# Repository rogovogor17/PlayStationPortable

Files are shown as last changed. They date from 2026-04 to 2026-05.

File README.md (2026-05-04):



[][platformio-url]
[][esp32-url]
[][cpp-url]
[][3dprint-url]
[][license-url]

<br />
<div align="center">
  <a href="https://github.com/rogovogor17/PlayStationPortable">
    
  </a>

  <h3 align="center">DIY PlayStation Portable (PSP)</h3>
  <h4 align="center">ESP32 + TFT Handheld with Battle City Game</h4>

<div align="center">

**[Getting Started](#getting-started)** • **[Hardware](#hardware)** • **[Game](#game-implementation)** • **[Case](#3d-printed-case)** • **[Roadmap](#roadmap)**

</div>
</div>

<details>
  <summary>Table of Contents</summary>
  <ol>
    <li><a href="#about-the-project">About The Project</a>
      <ul>
        <li><a href="#key-features">Key Features</a></li>
      </ul>
    </li>
    <li><a href="#getting-started">Getting Started</a>
      <ul>
        <li><a href="#prerequisites">Prerequisites</a></li>
        <li><a href="#firmware-upload">Firmware Upload</a></li>
      </ul>
    </li>
    <li><a href="#hardware">Hardware</a>
      <ul>
        <li><a href="#components">Components</a></li>
        <li><a href="#schematic--pinout">Schematic & Pinout</a></li>
      </ul>
    </li>
    <li><a href="#game-implementation">Game Implementation</a>
      <ul>
        <li><a href="#controls">Controls</a></li>
        <li><a href="#game-mechanics">Game Mechanics</a></li>
        <li><a href="#class-structure">Class Structure</a></li>
      </ul>
    </li>
    <li><a href="#3d-printed-case">3D Printed Case</a></li>
    <li><a href="#roadmap">Roadmap</a></li>
	<li><a href="#contributors">Contributors</a></li>
    <li><a href="#references">References</a></li>

  </ol>
</details>

---

## About The Project

DIY portable game console inspired by classic handhelds, built around the ESP32 microcontroller and a 480×320 TFT display. The device plays a custom Battle City‑like tank game and is enclosed in a fully 3D‑printed case. All hardware schematics, firmware, and 3D models are provided.

### Key Features

| Feature | Description |
| --- | --- |
| **Custom Hardware** | ESP32‑WROOM, ILI9488 TFT 3.5″/3.95″, 9 physical buttons, Li‑Po battery support |
| **Full Game** | Battle City clone with tanks, enemies, walls, bonuses, and increasing levels |
| **3D Printed Case** | Ergonomic shell designed in CAD, printed on a standard FDM printer |
| **PlatformIO Project** | Modern C++ (GNU++14), easy to build and upload |
| **Modular Code** | Object‑oriented design: `Tank`, `Bullet`, `Wall`, etc. |

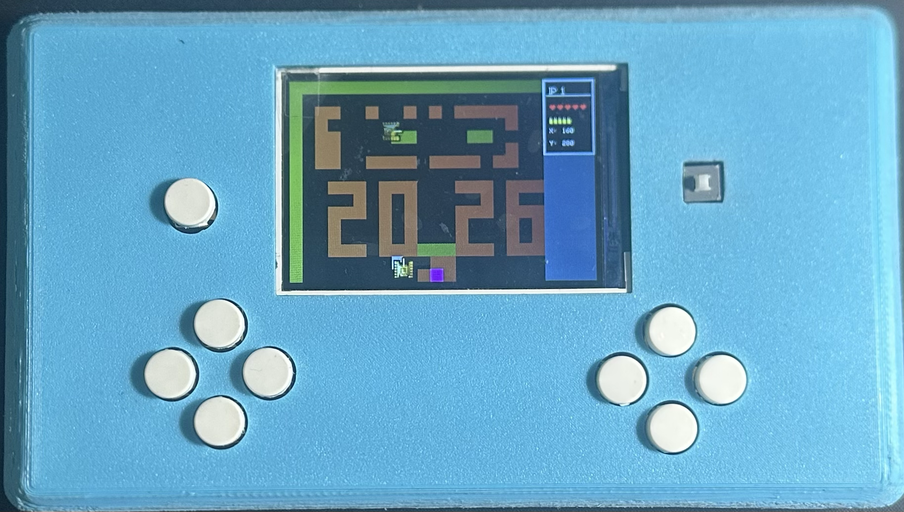
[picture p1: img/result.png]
Gameplay screenshot Battle City on ESP32


<p align="right">(<a href="#readme-top">back to top</a>)</p>

---

## Getting Started

### Prerequisites

| Tool / Hardware | Version / Spec | Purpose |
| --- | --- | --- |
| **PlatformIO** | Core 6.0+ / IDE VS Code | Build & upload firmware |
| **ESP32 board** | DOIT ESP32 DEVKIT V1 (WROOM‑32) | Main controller |
| **TFT display** | 3.5″/3.95″ ILI9488 SPI 480×320  | Graphics output |
| **9 tactile buttons** | Through‑hole 6×6 mm | Player input |
| **USB‑UART cable** | Type-C data cable | Programming & power |

### Firmware Upload

PlatformIO may be used in two different ways: as VS Code extension (recommended) or as command line interface (CLI).

#### 1. PlatformIO Core (CLI)

```bash
#Install using Python3
pip install -U platformio

#Checking PlatformIO
pio --version
```

#### 2. Open project

```bash
#Clone repo
git clone https://github.com/rogovogor17/PlayStationPortable
cd PlayStationPortable
```

#### 3. Port Settings

In file `platformio.ini` (line `upload_port`) you can add using port for your board, for example:

```ini
upload_port = COM9    			   (Windows)
upload_port = /dev/ttyUSB0  	   (Linux)
upload_port = /dev/cu.usbserial-*  (macOS)
```

If you comment the line, PlatformIO will try to identify the port automatically .

#### 4. Building and firmware

```bash
#CLI: in root directory
pio run --target upload --target monitor
```

First running may take a few minutes - PlatformIO will download necessary libraries and toolchain ESP32.

#### 5. Important notes for ESP32

> [!NOTE]
> If the firmware does not load, hold down the **BOOT** button (or press it once when the process starts) – this will put the ESP32 into programming mode.

> [!WARNING]
> When using a battery, the board power must be disconnected during flashing (to avoid conflicts).

> [!NOTE]
> After a successful boot, the game will appear on the display. If the screen is blank, check the display connection and the settings in the TFT_eSPI library's 'User_Setup.h' (the project already includes the correct configuration).

<p align="right">(<a href="#readme-top">back to top</a>)</p>

---

## Hardware

### Components

| Component | Model / Value | Quantity |
| --- | --- | --- |
| Microcontroller | ESP32‑WROOM‑32 (DOIT DevKit V1) | 1 |
| Display | TFT 3.5″ or 3.95″, ILI9488 controller | 1 |
| Buttons | D-Pad (4) + Fire + Start + 3 extra | 9 |
| Battery | 3.7 V Li‑Po | 2 |
| Charging module | TP4056 | 1 |
| Miscellaneous | Protoboard, wires, headers, Type-C | – |

### Schematic & Pinout

| ESP32 Pin | Function | Connected To |
| --- | --- | --- |
| GPIO 15 | TFT CS | Display CS |
| GPIO 2 | TFT DC | Display DC |
| GPIO 4 | TFT RST | Display RST |
| GPIO 23 | TFT MOSI | Display SDI/MOSI |
| GPIO 18 | TFT SCK | Display SCK |
| GPIO 19 | TFT MISO | Display SDO/MISO |
| GPIO 17 | Button UP | Pull‑up + button to GND |
| GPIO 33 | Button DOWN | Pull‑up + button to GND |
| GPIO 25 | Button LEFT | Pull‑up + button to GND |
| GPIO 19 | Button RIGHT | Pull‑up + button to GND |
| GPIO 27 | Button FIRE | Pull‑up + button to GND |
| GPIO 26 | Button START | Pull‑up + button to GND |
| GPIO 12 | Button EXTRA 1 | Pull‑up + button to GND |
| GPIO 13 | Button EXTRA 2 | Pull‑up + button to GND |
| GPIO 14 | Button EXTRA 3 | Pull‑up + button to GND |
| GND | Common ground  | All buttons, display |
| 3.3V | Power (logic)  | Display VCC |

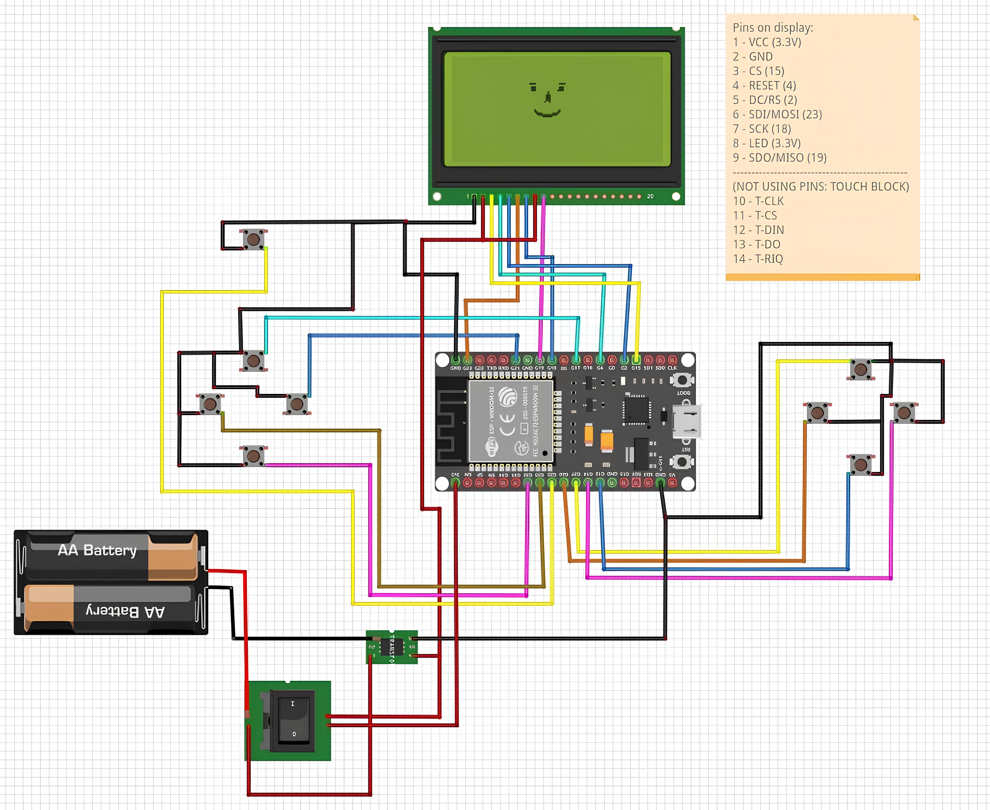
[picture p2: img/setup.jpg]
Schematic preview Schematic assemble


<p align="right">(<a href="#readme-top">back to top</a>)</p>

---

## Game Implementation

The firmware is written in **C++ (GNU++14)** and structured as a PlatformIO project. It uses the **TFT_eSPI** library for fast SPI graphics and **Arduino framework** for GPIO handling.

### Controls

| Button | Action |
| --- | --- |
| **D‑Pad** | Move player tank |
| **Fire** | Shoot |
| **Start** | Start game / Pause |
| **Extra 1** | (reserved for future use) |
| **Extra 2** | (reserved for future use) |
| **Extra 3** | (reserved for future use) |

### Game Mechanics

- **Player tank:** moves in four directions, shoots bullets, has health & ammunition.
- **Enemy tanks:** AI bots that move randomly and shoot.
- **Walls:** brick (destructible) and steel (indestructible).
- **Base (eagle):** must be protected from enemy fire.
- **Bonuses:** star (upgrade), shovel (temporary wall), helmet (invincibility), etc. (in future)

### Class Structure

The game logic is organised into several C++ classes that encapsulate behaviour and rendering.

<details>
<summary><b>class Tank</b> (click to expand)</summary>

```cpp
class Tank {
    const size_t max_health_, max_ammunition_;
    size_t health_, ammunition_;
    size_t x_pos, y_pos;
    size_t speed_;
    TankDirection direction_ = TankDirection::UP;

    TFT_eSPI& tft_;
    TFT_eSprite* tank_sprite_;
    uint16_t background_buffer_[DEFAULT_TANK_WIDTH * DEFAULT_TANK_HEIGHT];

public:
    Tank(size_t x, size_t y, size_t health, size_t ammo, size_t speed, TFT_eSPI& tft);
    ~Tank();

    void show(void);
    void move(int x, int y);
    void set_position(size_t x, size_t y);
    void set_direction(TankDirection direction);

    size_t get_x_pos() const;
    size_t get_y_pos() const;
    size_t get_speed() const;
    size_t get_health() const;
    size_t get_ammunition() const;
};
```

</details>

Additional classes: `Bullet`, `Wall`, `EnemyTank` (inherits from `Tank`), `GameBoard`, `GameState`.

All graphics use **TFT_eSprite** buffers to avoid flickering, and the display is updated only on changed tiles to meet the ESP32’s performance limits.

<p align="right">(<a href="#readme-top">back to top</a>)</p>

---

## 3D Printed Case

The console body was designed to house the ESP32 board, TFT panel, and all buttons. It consists of three parts:

- **Front shell** with cutouts for the display and buttons.
- **Back shell** with mounting cutout for the Type-C port.
- **Back cover** for getting access to batteries.

Printing settings (common for PLA):

- Layer height: 0.2 mm
- Infill: 20% grid
- Supports: for the edges of the supporting parts of the body

The model files are available in the `case/` directory.

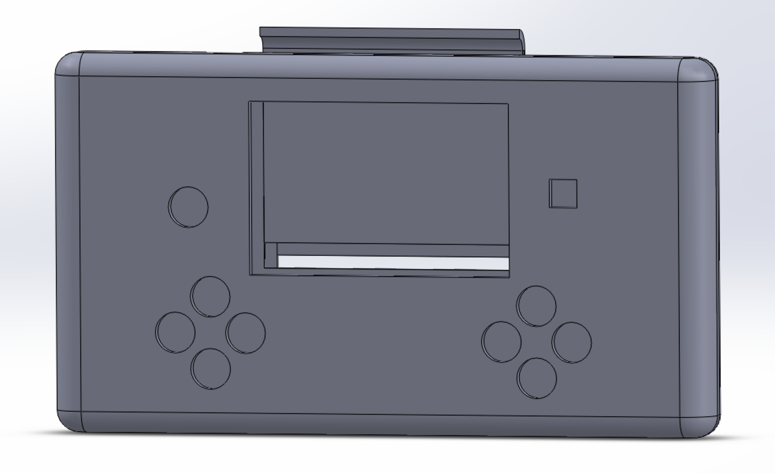
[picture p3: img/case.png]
Case preview Case assemble


<p align="right">(<a href="#readme-top">back to top</a>)</p>

---

## Roadmap

- [x] **Phase 1: Hardware**
  - [x] Schematic & prototype soldering
  - [x] Button & display integration

- [x] **Phase 2: Core Game**
  - [x] Player tank movement & shooting
  - [x] Map grid (12×8 cells, 40×40 px)
  - [x] Enemy AI, walls, base, bonuses

- [x] **Phase 3: Enclosure**
  - [x] 3D‑modeled case
  - [x] FDM printing and assembly

- [ ] **Phase 4: Polish**
  - [ ] Sound effects (buzzer or speaker)
  - [ ] Battery indicator & power management
  - [ ] Multiple levels and high‑score save

<p align="right">(<a href="#readme-top">back to top</a>)</p>

---

## Contributors

The project was created and developed by enthusiasts who believe in open source and the DIY spirit.

| Author | Role | Tasks | Contacts |
| --- | --- | --- | --- |
| Alexander Starostin | Hardware Lead  | Circuit design and soldering | [GitHub](https://github.com/Alexandr26Starostin) |
| Michael Movsesyan | Game Developer | Game design, Game code | [GitHub](https://github.com/aywert) |
| Anatoliy Rogov | 3D Designer | Case modeling/printing, components selection/ordering | [GitHub](https://github.com/rogovogor17) |

---

## References

1. **PlatformIO** — [platformio.org](https://platformio.org/)
2. **TFT_eSPI library** — [github.com/Bodmer/TFT_eSPI](https://github.com/Bodmer/TFT_eSPI)
3. **Inspiration** — classic Battle City (NES, 1985)

<p align="right">(<a href="#readme-top">back to top</a>)</p>

---

<div align="center">
  <sub>© 2026 — DIY PlayStation Portable</sub>
</div>

[platformio-shield]: https://img.shields.io/badge/PlatformIO-6.0+-F58220?style=for-the-badge&logo=platformio&logoColor=white
[platformio-url]: https://platformio.org/
[esp32-shield]: https://img.shields.io/badge/ESP32-DOIT_DevKit_V1-00B0FF?style=for-the-badge&logo=espressif&logoColor=white
[esp32-url]: https://www.espressif.com/en/products/socs/esp32
[cpp-shield]: https://img.shields.io/badge/C++-GNU++14-00599C?style=for-the-badge&logo=c%2B%2B&logoColor=white
[cpp-url]: https://isocpp.org/
[3dprint-shield]: https://img.shields.io/badge/3D_Printed-FDM-orange?style=for-the-badge&logo=thingiverse&logoColor=white
[3dprint-url]: https://www.thingiverse.com/
[license-shield]: https://img.shields.io/badge/License-MIT-green.svg?style=for-the-badge
[license-url]: LICENSE.txt

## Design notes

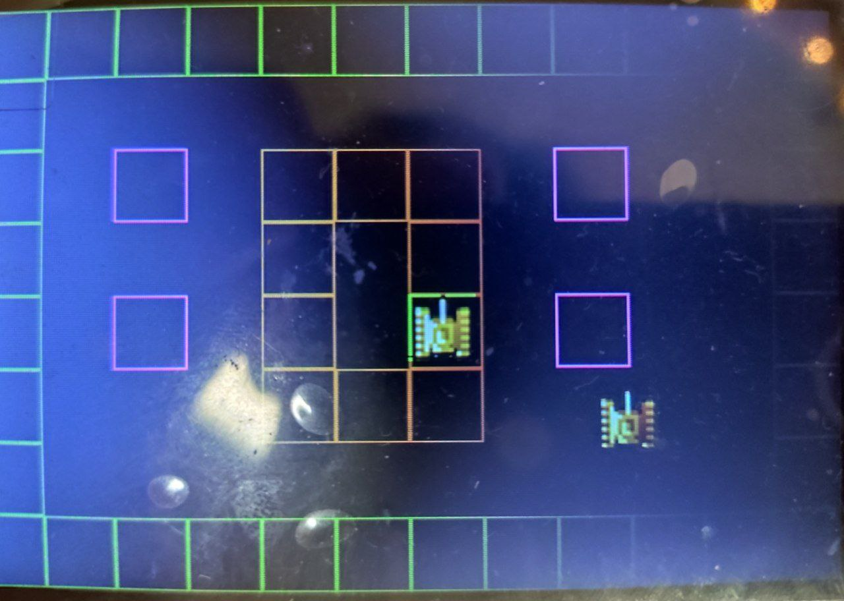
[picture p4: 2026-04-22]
img/image.png

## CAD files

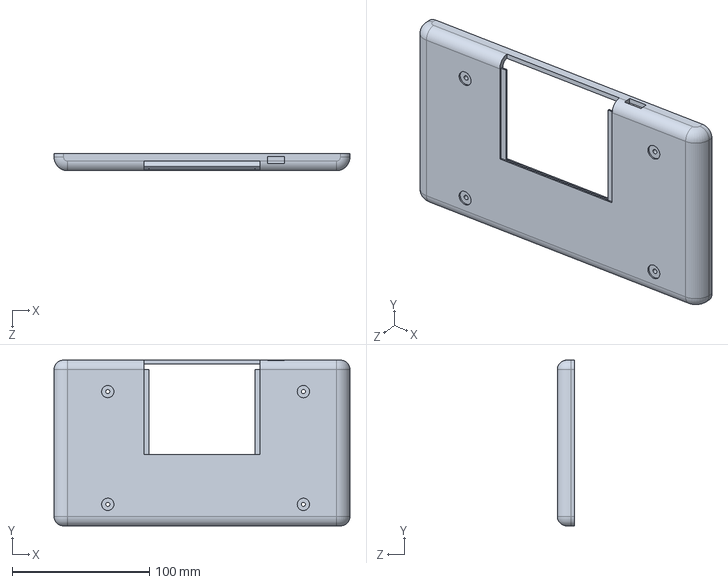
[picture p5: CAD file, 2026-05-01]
case/FrameDownMain.STEP
216.0 x 121.0 x 12.8 mm

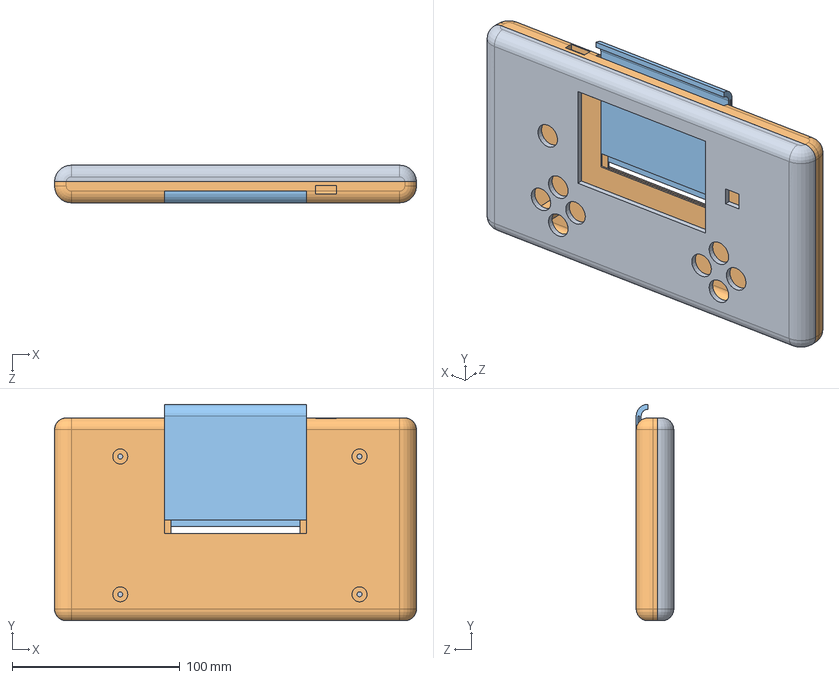
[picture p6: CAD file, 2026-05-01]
case/PSP.SLDASM
216.0 x 129.2 x 22.5 mm
FrameUP
FrameDownMain
FrameDownCover

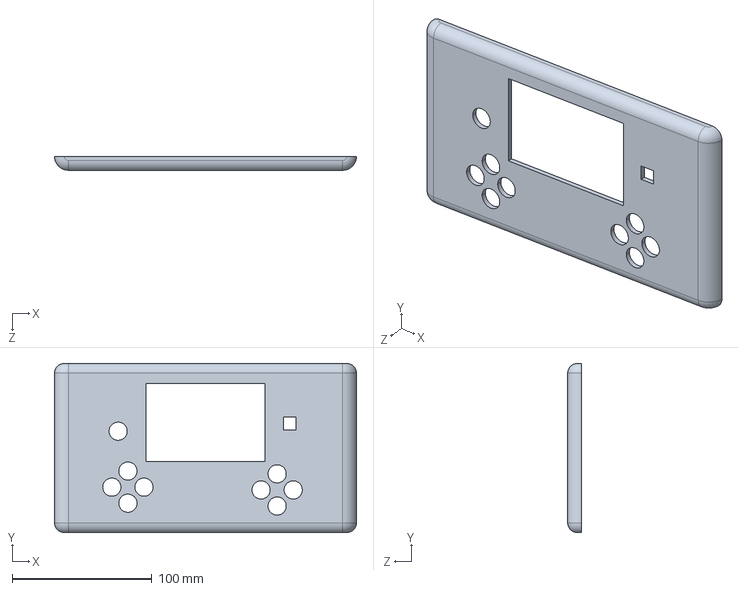
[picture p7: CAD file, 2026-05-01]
case/FrameUP.STEP
216.0 x 121.0 x 9.75 mm

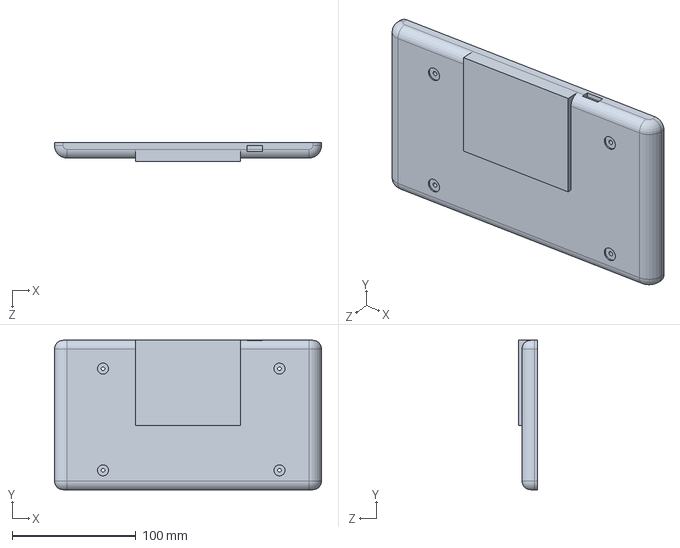
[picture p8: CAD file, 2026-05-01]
case/FrameDown.SLDPRT
216.0 x 121.0 x 15.8 mm

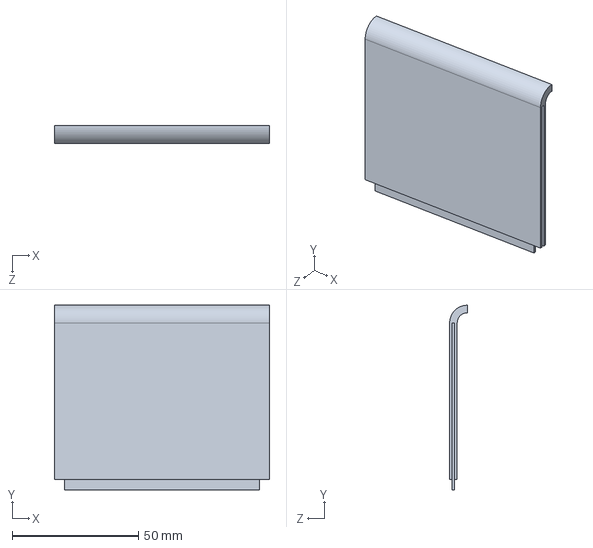
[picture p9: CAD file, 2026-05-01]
case/FrameDownCover.STEP
85.0 x 73.0 x 7.00 mm

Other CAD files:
case/FrameDownCover.SLDPRT
case/FrameDownMain.SLDPRT
case/FrameUP.SLDPRT

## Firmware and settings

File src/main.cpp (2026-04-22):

#include <SPI.h>
#include <TFT_eSPI.h> // Hardware-specific library

#include "../include/game.hpp"

TFT_eSPI tft = TFT_eSPI();       // Invoke custom library

void setup(void) {
  delay(1000);
  tft.init();
  tft.fillScreen(TFT_BLACK); // sets screen Black
  tft.setTextColor(TFT_WHITE);
  tft.setRotation(1);            // Album orientation
  tft.setSwapBytes(true);
  tft.drawString("World of Tanks", X_CENTER-70, Y_CENTER, 4); //Print string in the center
  //tft.drawString("Ura", X_CENTER-70, Y_CENTER, 4); //Print string in the center
  delay(1000); // delay for 2 seconds to show the name of the game
  tft.fillScreen(TFT_BLACK);

  

  Serial.begin(115200); // setting velocity of communication with pins
  //CountDown(tft);
  
}

void loop() {
  while (true) {
    Game TANKS(tft);
    TANKS.start();
  };
}

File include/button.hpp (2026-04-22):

#ifndef BUTTON_CLASS
#define BUTTON_CLASS

#include <stdlib.h>
#include <vector>
#include <TFT_eSPI.h>

enum ButtonID {
  BTN_UP,
  BTN_DOWN,
  BTN_LEFT,
  BTN_RIGHT,
  BTN_X,
  BTN_Y,
  BTN_A,
  BTN_B,
  BTN_PAUSA,
  BTN_COUNT  // Number of buttons
};

constexpr int BTN_UP_PIN    = 17;
constexpr int BTN_DOWN_PIN  = 32; 
constexpr int BTN_RIGHT_PIN = 21; 
constexpr int BTN_LEFT_PIN  = 33; 

constexpr int BTN_X_PIN     = 26;  
constexpr int BTN_Y_PIN     = 27;  
constexpr int BTN_A_PIN     = 12;  
constexpr int BTN_B_PIN     = 14;  

constexpr int BTN_PAUSA_PIN = 25;  

class Button final {
    size_t pin_;
    
    public:
        int status_;
        
        Button(size_t pin) : pin_(pin), status_(false)  {
            pinMode(pin, INPUT_PULLUP);
        }

        void update() {
            status_ = digitalRead(pin_) == LOW; // true when button is pressed, false when button is not pressed
        }
};


#endif

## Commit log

2026-02-10 not tested: yet to solder console
2026-02-11 tested privious version: it worked incorrectly for it was not oriented correctly; It is a version were we found out that our device esp32 couldn't update full screen due to lack of ram. Decided to pu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
    [main.cpp, tank.hpp]
2026-02-12 tanks can be moved by buttons: tested only on BUTTUN_DOWN as other buttons are not yet connected
2026-03-04 added collisions and bullets; Faced a problem of warping of the image bullets touches
    [button.hpp, main.cpp]
2026-03-05 Added Collision Manager and class Collidable; need to elaborate on details of Buttons update and On_collision method both for Tank and Button
    [tank.hpp]
2026-03-05 united class Drawable and Collidable; Now its called Entity; Fixed the problem of the tank being stopped by his own bullets
    [tank.hpp]
2026-04-01 fixed the problem of hanging pointers in Collide manager
    [tank.hpp]
2026-04-04 Added ending of the game; If base is destroyed user will get the massage that game is over; And will launch the game again; Now game obtain copy of the map in order to have any samples of the Game be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
2026-04-09 now there are 3 levels with different amounts of bot with random characteristics; It switches to next level aoutomatically
